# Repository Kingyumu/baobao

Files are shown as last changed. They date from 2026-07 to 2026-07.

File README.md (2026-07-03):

# 桌面天气站完整制作指南

> 从零到成品的制作手册：备齐材料 → 接线 → 编译烧录固件 → 装外壳 → 配网送礼。  
> 本文档**不包含项目源代码**，固件逻辑见仓库 `src/` 目录及源码注释。

**主控：** Raspberry Pi Pico 2 W（RP2350，板载 WiFi）  
**传感器：** BME280（温湿度气压）+ DS3231（RTC）  
**显示：** 3.5 寸 ILI9488 彩色 TFT（480×320）  
**交互：** 无源蜂鸣器 + TTP223 触摸

---

## 目录

1. [制作流程一览](#1-制作流程一览)
2. [成品功能说明](#2-成品功能说明)
3. [材料清单](#3-材料清单)
4. [开发环境搭建](#4-开发环境搭建)
5. [硬件接线](#5-硬件接线)
6. [固件说明（项目能做什么）](#6-固件说明项目能做什么)
7. [编译、烧录与首次验证](#7-编译烧录与首次验证)
8. [外壳制作与组装](#8-外壳制作与组装)
9. [送礼前可选配置](#9-送礼前可选配置)
10. [常见问题排查](#10-常见问题排查)
11. [附录 A：接线速查表](#附录-a接线速查表)
12. [附录 B：随礼使用说明书](#附录-b随礼使用说明书)

---

## 1. 制作流程一览

按顺序完成以下步骤，即可得到可送礼的成品：

| 步骤 | 做什么 | 预计时间 | 完成标志 |
| ----- | --- | --- | --- |
| ① 采购  | 按材料清单买齐模块与工具 | 1–3 天（等快递） | 所有模块到手 |
| ② 搭环境 | 安装 Rust、交叉编译工具链、probe-rs | 30–60 分钟 | `cargo`、`probe-rs` 命令可用 |
| ③ 接线  | 面包板或洞洞板连接各模块 | 30–60 分钟 | 对照检查清单全部打勾 |
| ④ 烧录  | 克隆项目、编译、写入 Pico 2 W | 15–30 分钟 | 屏幕出现启动动画 |
| ⑤ 配网  | 手机连热点、网页填家里 WiFi | 5 分钟 | 连上 WiFi，显示室外天气 |
| ⑥ 外壳  | 3D 打印或手工盒体，固定模块 | 1–2 小时 | 线材不 loose，屏幕对齐窗口 |
| ⑦ 送礼  | 打印附录 B 说明书，装盒 | 15 分钟 | 对方插电即用 |

**推荐顺序：** 先面包板裸机调通（③④⑤），确认功能正常后再做外壳（⑥），避免返工。

---

## 2. 成品功能说明

### 2.1 功能一览

| 功能 | 说明 | 是否需要 WiFi |
| --- | --- | --- |
| 室内温湿度 + 气压 | BME280 实时测量 | 否 |
| 精确时钟 | DS3231，断电靠纽扣电池走时 | 否（联网可 NTP 校准） |
| 圆形时钟 + 双页 UI | 轻触切换本地页 / 对方城市页；两页均保留时钟圆盘 | 否 |
| 双城室外天气 | 本地城市 + 对方城市（编译前配置城市码） | 是 |
| 表情动画 | 随温度、天气、气压趋势变化 | 部分依赖联网天气 |
| 室外天气 | 中国天气网，本地 + 对方两城数据 | 是 |
| 纪念日 / 生日 | 到日弹祝福 + 旋律 | 否 |
| 闹钟 / 整点报时 | 软件检测时间后蜂鸣 | 否 |
| 气压趋势与变天预警 | 本地气压趋势（变天预警仅本地页显示） | 否 |
| 触摸互动 | 短触切页；长按 2 秒爱心；长按 5 秒清除 WiFi | 否 |
| 手机配网 | 热点 + 网页，无需改代码烧录 | 首次或换 WiFi 时 |
| BLE 传感器广播 | 手机可连读室内温湿度（联网成功后开启） | 否（蓝牙独立） |

### 2.2 屏幕布局

设备共有 **两页**，左侧均为模拟时钟圆盘，右侧内容随页面切换。轻触一下在两页间来回切换。

**本地页（默认）**

```
┌──────────────────────────────────────────────────┐
│                                          [WiFi]  │
│          12                                      │
│        ·   ·       ☀ 余杭                        │
│      9  ⬡  3       室外 28°C · 晴                │
│        ·   ·       室内比室外凉 2.3°C             │
│          6         室内环境                       │
│                    😊 25.3°C  💧 45%             │
│       12:30:45     📊 1013 hPa  ↑ 转晴            │
│  室温曲线 (~2h)                   😊              │
│  ┌────────────────┐                             │
│  │    ～折线～     │                             │
│  └────────────────┘                             │
│             2026年7月1日 周二                      │
│ [本地] 轻触切换 长按爱心                            │
└──────────────────────────────────────────────────┘
```

**对方城市页**

```
┌──────────────────────────────────────────────────┐
│                                          [WiFi]  │
│          12                                      │
│        ·   ·       Ta在·北京                     │
│      9  ⬡  3       ☀ 22.5°C                     │
│        ·   ·       晴 · 湿度 40%                  │
│          6         比这里凉 5.5°C                 │
│                    我们在一起已经                  │
│       12:30:45        520天了                     │
│             2026年7月1日 周二                      │
│ [对方] 轻触切换 长按爱心                            │
└──────────────────────────────────────────────────┘
                        480 × 320
```

左侧：模拟时钟 + 数字时间 + **室温折线图**（约 2 小时，每分钟采样）  
右侧：本地页显示本城室外 + 室内环境；对方页显示 Ta 所在城市室外天气 + **在一起天数**（数字略大）  
右下：表情（本地页随本城环境，对方页随对方天气）  
底部：日期；左下角页码提示

### 2.3 系统结构（帮助理解接线）

```
  BME280 ──I2C──┐
  DS3231 ──I2C──┼──► Pico 2 W ──SPI──► ILI9488 屏幕
                │         │
  蜂鸣器 ──GPIO─┤         ├── WiFi（板载）──► 天气 / NTP
  触摸   ──GPIO─┘         └── BLE（板载，联网后广播传感器）
```

---

## 3. 材料清单

### 3.1 核心组件

| 物料  | 型号 | 数量  | 参考价 | 说明 |
| --- | --- | --- | --- | --- |
| 主控  | **Raspberry Pi Pico 2 W**  | 1 | ¥45 | 必须带 W（WiFi），RP2350 |
| 传感器 | **BME280 模块**（I2C，六脚） | 1 | ¥18 | 勿买成 BMP280（无湿度） |
| 显示屏 | **3.5 寸 ILI9488 TFT**（SPI） | 1 | ¥55 | 480×320，驱动 ILI9488 |
| 时钟  | **DS3231 模块**（带 CR2032） | 1 | ¥12 | I2C 地址 0x68 |
| 蜂鸣器 | **无源蜂鸣器模块** | 1 | ¥2  | 可播放旋律；有源只能「嘀」 |
| 触摸  | **TTP223 触摸模块** | 1 | ¥3  | 电容触摸，轻触即可 |

### 3.2 辅助材料

| 物料 | 数量 | 说明 |
| --- | ----- | --- |
| 面包板 830 孔 | 1 | 调试阶段用 |
| 杜邦线 公对母 / 公对公 | 20+ 根 | 你已有 40 根公对公通常够用 |
| USB **数据线** Type-C | 1 | 必须能传数据，不能纯充电线 |
| 3D 打印外壳或手工盒 | 1 套 | 见第 8 章 |
| 热熔胶 / 螺丝 | 若干 | 固定模块 |

**预算参考：** 约 ¥140–170（不含 3D 打印运费）

### 3.3 工具

- 电脑（Windows / macOS / Linux）
- 烙铁 + 焊锡（模块无排针时）
- 万用表（可选，查通断）
- 热熔胶枪（装外壳）

### 3.4 为什么选这些件

| 对比  | 不推荐 | 推荐 | 原因 |
| --- | --- | --- | --- |
| 主控  | Pico W (RP2040) | **Pico 2 W** | 520KB RAM 够驱动 3.5 寸彩屏 |
| 温湿度 | DHT11 | **BME280** | 精度高、I2C 稳定、带气压 |
| 屏幕  | 小 OLED | **3.5 寸 ILI9488** | 送礼观感好、480×320 彩色 |

---

## 4. 开发环境搭建

在**你自己的电脑**上完成（收礼人不需要装这些）。

### 4.1 安装 Rust

**Windows（PowerShell）：**

```powershell
winget install Rustlang.Rustup
```

或从 [https://www.rust-lang.org/tools/install](https://www.rust-lang.org/tools/install) 下载安装器。

**macOS / Linux：**

```bash
curl --proto '=https' --tlsv1.2 -sSf https://sh.rustup.rs | sh
```

验证：

```bash
rustc --version
cargo --version
```

### 4.2 安装嵌入式工具链

```bash
rustup target add thumbv8m.main-none-eabihf
cargo install probe-rs-tools
cargo install flip-link
```

### 4.3 Windows：USB 驱动（probe-rs 烧录）

1. 下载 [Zadig](https://zadig.akeo.ie/)
2. 按住 Pico **BOOTSEL**，插入 USB，松开
3. Zadig 中选择 Pico 设备，驱动选 **WinUSB**，安装

### 4.4 获取项目代码

```bash
git clone <你的仓库地址> baobao
cd baobao
```

### 4.5 环境自检

```bash
rustc --version
cargo --version
probe-rs --version
```

三项均有输出即可进入接线与烧录。

---

## 5. 硬件接线

### 5.1 原则

- **共地：** 所有模块 GND 接 Pico GND  
- **I2C 共享：** BME280 与 DS3231 共用 GP0(SDA)、GP1(SCL)，靠不同地址区分  
- **WiFi：** Pico 2 W 板载，**无需接线**  
- **屏幕 SPI：** 独立一组线，不要与 I2C 混接

### 5.2 接线总览图

```
                    Raspberry Pi Pico 2 W
                    ┌────────────────────────────────────┐
  3V3 (Pin36) ──┬──┼──────┬──────┬──────────┬──────────┼── ...
  GND (Pin38) ──┼──┼──────┼──────┼──────────┼──────────┼── ...
  GP0 (Pin1)  ──┼──┼──────┼──────┼──────────┼──────────┼── ...
  GP1 (Pin2)  ──┼──┼──────┼──────┼──────────┼──────────┼── ...
  GP6 (Pin9)  ──────────────────────────────────────────┼── ...
  GP7 (Pin10) ──────────────────────────────────────────┼── ...
  GP8~GP11    ──────────────────────────────────────────┼── SPI → TFT
                    └────────────────────────────────────┘
         │           │          │              │
    BME280+DS3231  蜂鸣器+触摸   ILI9488 TFT    WiFi 板载
```

### 5.3 引脚对照表

| Pico 引脚 | 功能 | 连接 |
| --- | --- | --- |
| GP0 (Pin1) | I2C SDA  | BME280 SDA、DS3231 SDA |
| GP1 (Pin2) | I2C SCL  | BME280 SCL、DS3231 SCL |
| GP6 (Pin6) | GPIO 出 | 蜂鸣器 I/O |
| GP7 (Pin7) | GPIO 入 | 触摸 I/O |
| GP8 (Pin8) | GPIO 出 | ILI9488 DC |
| GP9 (Pin9) | GPIO 出 | ILI9488 CS |
| GP10 (Pin10) | SPI SCK  | ILI9488 SCK |
| GP11 (Pin11) | SPI MOSI | ILI9488 MOSI |
| 3V3 (Pin36)  | 电源 | BME280、DS3231、触摸、TFT RST/LED 等 |
| 5V (Pin40) | 电源 | 部分 TFT 也可用 5V |
| GND (Pin38)  | 地 | 所有模块 GND |

### 5.4 各模块接线要点

**BME280：** VCC、GND、SDA、SCL 四线即可；确认芯片丝印为 BME280；I2C 地址一般为 **0x76**。

**DS3231：** 同上四线；装好 **CR2032** 纽扣电池；地址 **0x68**。

**ILI9488：** SCK、MOSI、CS、DC、VCC、GND；RST 与 LED 可接 3V3 常亮；MISO 可不接。模块丝印顺序可能不同，**以模块标注为准**。

**无源蜂鸣器：** I/O → GP6；VCC 建议 **5V**；GND 共地。

**TTP223：** I/O → GP7；触摸时输出高电平。

### 5.5 接线检查清单（烧录前必做）

- BME280、DS3231 的 SDA→GP0，SCL→GP1  
- ILI9488：SCK→GP10，MOSI→GP11，CS→GP9，DC→GP8  
- ILI9488 背光 LED、RST 接 3V3（或按模块说明）  
- 蜂鸣器 I/O→GP6  
- 触摸 I/O→GP7  
- 所有 GND 共地  
- DS3231 纽扣电池已装  
- USB 线为**数据线**

---

## 6. 固件说明（项目能做什么）

仓库里的固件是预写好的程序，你**不需要改代码也能做出成品**（配网用手机完成）。下面说明固件行为，方便排查问题。

### 6.1 项目里有哪些模块（仅文件名，方便查注释）

| 文件 | 作用 |
| --- | --- |
| `main.rs` | 启动流程、主循环、触摸逻辑 |
| `config.rs` | 城市码、纪念日、闹钟等可调参数 |
| `sensors.rs` | BME280、DS3231 驱动 |
| `display.rs` / `render.rs` | 屏幕驱动与界面绘制 |
| `network.rs` | WiFi、NTP、网络天气 |
| `wifi_store.rs` | Flash 保存最多 5 个 WiFi（最近使用的优先） |
| `provisioning.rs` | 热点 + 网页配网 |
| `state.rs` | 气压趋势、闹钟、纪念日等业务状态 |
| `buzzer.rs` | 提示音与旋律 |
| `ble.rs` | 蓝牙广播室内传感器（联网成功后启动） |

详细 Rust 学习注释见各文件顶部说明。

### 6.2 上电后发生什么

1. 屏幕显示 Loading 动画与「天气站启动中…」
2. 读取 Flash 里记住的 WiFi，**按最近使用顺序**逐个尝试连接
3. **若全部连不上** → 进入配网模式（见 7.3），此时**不开启 BLE**
4. **若连上** → 启动 BLE、NTP 对时、拉取天气 → 双声蜂鸣表示就绪
5. 进入主循环：每秒刷新显示，定期更新天气与 NTP

### 6.3 配网模式（送礼核心）

| 项目 | 内容 |
| ----- | --- |
| 热点名称  | `Baobao`（开放，无密码） |
| 设备 IP | `192.168.4.1` |
| 操作 | 手机连热点 → 浏览器打开上述 IP → 填家里 WiFi 名和密码 → 提交 |
| 成功 | 设备验证能连上 → 写入 Flash → 自动重启 → 正常模式 |
| 记忆 | 最多记住 **5 个** WiFi；满员时淘汰**最久未用**的网络 |
| 重新配网  | 长按触摸 **5 秒** → 清除全部 WiFi → 重启进入配网 |

屏幕配网页也会提示上述步骤。

### 6.4 触摸操作

| 操作 | 效果 |
| --- | --- |
| 短按 | 切换页面：本地 ↔ 对方城市（两页均保留时钟圆盘） |
| 长按约 2 秒 | 爱心动画 + 短促提示音 |
| 长按约 5 秒 | 两声长「嘀」→ 清除 WiFi 记忆 → 重启配网 |

### 6.5 网络相关

- **WiFi：** 仅 2.4GHz  
- **室外天气：** 中国天气网；烧录前在 `config.rs` 配置**本地城市码**与**对方城市码**（及显示名称）  
- **NTP：** 默认国家授时中心，联网后自动校准 DS3231  
- **断网：** 室内温湿度、时钟、表情、闹钟仍可用；室外天气不更新

### 6.6 表情与气压

- 表情随温度、网络天气、**气压趋势**变化  
- 气压持续下降且偏低时可能触发**变天预警**（屏幕提示 + 蜂鸣）  
- 不联网也能根据本地气压趋势显示「转晴 / 转阴」类提示

---

## 7. 编译、烧录与首次验证

### 7.1 编译

在项目根目录：

```bash
cargo check          # 快速检查
cargo build --release # 生成固件
```

### 7.2 烧录（推荐 probe-rs）

1. 按住 **BOOTSEL**，USB 连接电脑，松开
2. 执行：

```bash
cargo run --release
```

自动编译、烧录并运行。

**UF2 方式（无需 probe-rs）：**  
编译后找到 `target/thumbv8m.main-none-eabihf/release/weather_station.uf2`，BOOTSEL 模式下拖入 Pico 虚拟 U 盘。

### 7.3 首次验证清单

| 现象 | 是否正常 |
| --- | --- |
| 屏幕亮，有启动动画 | ✅ |
| 约 1 秒后双声蜂鸣  | ✅（已连上 WiFi 时） |
| 或进入配网界面 | ✅（Flash 无 WiFi 时，见 6.3） |
| 左侧时钟走动 | ✅（需 DS3231 正常；联网后 NTP 更准） |
| 室内温湿度有数值 | ✅（BME280 正常） |
| 短触屏幕有「嘀」且换页 | ✅ |

### 7.4 首次配网步骤（模拟收礼人操作）

1. 上电后若显示配网说明，用手机 WiFi 列表找到 **Baobao** 并连接
2. 浏览器访问 **[http://192.168.4.1](http://192.168.4.1)**（部分手机会自动弹出配网页）
3. 填写家里 **2.4GHz WiFi** 的名称和密码 → 保存
4. 等待「配网成功」→ 设备重启 → 应显示 WiFi 图标为已连接、室外温度出现

### 7.5 查看运行日志（排查用）

另开终端：

```bash
probe-rs attach --chip RP2350
```

正常时可见 BME280 初始化、WiFi 连接、NTP、天气等 INFO 日志（需固件开启 defmt）。

---

## 8. 外壳制作与组装

### 8.1 模块实测尺寸

先用卡尺量你手上每个模块的实际尺寸，以下为参考值：

| 模块 | 大约尺寸 (长×宽×高) | 备注 |
|---|---|---|
| ILI9488 3.5 寸屏 | 85 × 55 × 4 mm | 可视区约 73 × 49 mm |
| Pico 2 W | 51 × 21 × 4 mm | USB 口在一端 |
| BME280 模块 | 13 × 11 × 2 mm | 需要透气孔 |
| DS3231 模块 | 38 × 14 × 6 mm | 含纽扣电池座 |
| TTP223 触摸模块 | 24 × 16 × 2 mm | 金属感应面朝外 |
| 蜂鸣器模块 | 22 × 15 × 12 mm | 出声孔朝外 |

**外壳建议尺寸：** 100 × 80 × 40 mm（长 × 宽 × 高），壁厚 2mm。

### 8.2 外壳结构设计

外壳分**前面板**和**底壳**两部分（卡扣或螺丝合体）。

**前面板（屏幕面）**

```
┌──────────────────────────────────────┐
│  ┌────────────────────────────────┐  │
│  │                                │  │
│  │         屏幕窗口                │  │
│  │      75 × 51 mm               │  │
│  │   （比可视区四周大 1-2mm）        │  │
│  │                                │  │
│  └────────────────────────────────┘  │
│                                      │
│                 ◯ ← 触摸区           │
│              （TTP223 金属面对应位置） │
└──────────────────────────────────────┘
```

**底壳 / 后面**

```
┌──────────────────────────────────────┐
│                                      │
│  ◎ 透气孔 φ5-6mm   ← BME280 对应位置 │
│                                      │
│  □ USB Type-C 开口  ← Pico USB 对齐  │
│     约 9 × 4 mm                     │
│                                      │
│  ○ 出声孔 φ3-5mm × 2-3 个 ← 蜂鸣器  │
│                                      │
│  ⊚ 螺丝柱 M3 × 4（可选）            │
└──────────────────────────────────────┘
```

**必须开的孔/窗口：**

| 开孔 | 位置 | 尺寸 | 原因 |
|---|---|---|---|
| 屏幕窗口 | 前面板中央 | 75 × 51 mm | 显示内容可见 |
| USB 口 | 后面或侧面 | 9 × 4 mm | 供电线穿入 |
| 透气孔 | 底面，BME280 附近 | φ5-6 mm | 气压测量需空气流通 |
| 触摸区 | 前面板，TTP223 对应处 | 壁厚 ≤ 0.8mm 或开小孔 | 电容感应需手指靠近 |

**可选开孔：**

| 开孔 | 位置 | 尺寸 | 原因 |
|---|---|---|---|
| 蜂鸣器出声孔 | 侧面或底面 | φ3-5 mm × 2-3 个 | 声音更大 |
| 螺丝孔 | 四角 | M3 通孔 | 固定前后壳 |

### 8.3 方案选择

| 方案 | 难度  | 效果 | 费用 |
| --- | --- | --- | --- |
| 3D 打印 PLA | ★★☆ | 推荐，可定制触摸区与开孔 | 代打 ¥10–30  |
| 亚克力盒 | ★☆☆ | 快速，内部可见 | ¥5–15 |
| 纸盒 / 木盒 | ★☆☆ | 手工温馨感 | 几乎免费 |

无 3D 打印机可用嘉立创 3D 打印、淘宝代打，上传 STL 文件即可，约 ¥10–30。

### 8.4 建模工具（三选一）

**方案 A：TinkerCAD（零基础推荐，免费网页版）**

1. 打开 https://www.tinkercad.com → 注册 → 创建 3D 设计
2. 放一个 Box（100 × 80 × 40mm）作为外壳主体
3. 内部放一个 Hole Box（96 × 76 × 36mm）挖空（壁厚 2mm）
4. 前面放 Hole Box（75 × 51mm，深 2mm）挖屏幕窗口
5. 后面放 Hole Box（9 × 4mm）挖 USB 口
6. 底面放 Hole Cylinder（φ5mm）挖透气孔
7. 触摸区位置壁厚减薄到 0.8mm（或放 Hole Cylinder 开小圆孔）
8. 选中全部 → Group → 导出 `.stl`

**方案 B：Fusion 360（进阶推荐，免费个人版）**

1. 下载 https://www.autodesk.com/products/fusion-360/personal
2. 草绘外框矩形 → 拉伸 40mm
3. 草绘内框 → 拉伸做布尔减法挖空
4. 各面分别草绘开孔形状 → 拉伸切除
5. 可做卡扣、螺丝柱、加强筋等细节
6. 导出 `.stl`

**方案 C：用现成模型修改**

在 Printables（https://www.printables.com）或 Thingiverse 搜索：
- `"Pico weather station case"`
- `"3.5 inch TFT case"`
- `"ILI9488 enclosure"`

找接近的模型下载，在 TinkerCAD 或 MeshMixer 中修改尺寸和开孔。

### 8.5 打印参数建议

| 参数 | 推荐值 | 说明 |
|---|---|---|
| 材料 | PLA | 最易打印，室内够用 |
| 层高 | 0.2mm | 精度与速度平衡 |
| 填充 | 15–20% | 外壳不需要太实心 |
| 壁厚 | 2mm | 2–3 圈外壳，足够强度 |
| 支撑 | 有悬空时开启 | 屏幕窗口边缘可能需要 |
| 打印方向 | 底面朝下 | 屏幕窗口朝上打印，减少支撑 |

### 8.6 组装顺序

```
第 1 步：去支撑、打磨外壳
    ↓
第 2 步：固定 Pico（热熔胶或螺丝，USB 口对准后壳开孔）
    ↓
第 3 步：固定 TFT 屏幕（屏幕对准前窗，四周热熔胶固定）
    ↓
第 4 步：放置 BME280（对准透气孔，不要密封）
    ↓
第 5 步：固定 DS3231、蜂鸣器、触摸模块
         （触摸金属面朝向前壳指定位置）
    ↓
第 6 步：接线、理线，热熔胶加固避免短路
    ↓
第 7 步：合盖，底脚贴防滑垫
```

**注意事项：**

- BME280 **不能密封**，否则气压测量不准
- 触摸模块金属感应面必须**靠近壳体表面**（≤2mm），否则感应不灵敏
- 蜂鸣器出声孔要**朝外**，不能被其他模块挡住
- 热熔胶固定时**远离屏幕表面**，避免烫伤偏光片

### 8.7 送礼包装建议

- 打印 [附录 B](#附录-b随礼使用说明书) 放入盒内
- 附 USB Type-C 数据线、备用 CR2032 纽扣电池
- 盒内留简短手写卡片即可
- **无需**教对方改代码或烧录 — 设备用手机配网

---

## 9. 送礼前可选配置

以下在**烧录前**于电脑上改项目里的 `**src/config.rs`**，改完重新 `cargo run --release` 烧录。  
**WiFi 不必在此填写**——收礼人用手机配网即可。

| 配置项 | 用途 | 默认值提示 |
| --- | --- | --- |
| `CITY_CODE` / `LOCAL_CITY_NAME` | 设备所在城市码与显示名 | 可在 weather.com.cn 查 URL 中的数字 |
| `PARTNER_CITY_CODE` / `PARTNER_CITY_NAME` | 对方所在城市码与显示名 | 如异地恋场景填对方城市 |
| `LOVE_START_YEAR` / `MONTH` / `DAY` | 恋爱起始日（对方页「在一起 n 天」） | 含起始日当天为第 1 天 |
| `BIRTHDAY_MONTH` / `BIRTHDAY_DAY` | 生日祝福 | 改成对方生日 |
| `ANNIVERSARIES` | 情人节、纪念日等  | 可增删条目 |
| `ALARM_HOUR` / `ALARM_MINUTE` | 闹钟 | 可按需开关 `ALARM_ENABLED` |
| `HOURLY_CHIME_`* | 整点报时时段 | 默认 8:00–21:00 |
| `BLE_ENABLED` | 是否广播蓝牙传感器 | 默认关闭 |
| `WIFI_SSID` / `WIFI_PASSWORD` | 仅开发兜底 | 保持占位符即可，靠配网 |

**城市码查询：** 打开 [https://www.weather.com.cn/](https://www.weather.com.cn/) 搜索城市，地址栏如 `.../101210106.shtml` → 代码为 `101210106`。

---

## 10. 常见问题排查

### 10.1 编译 / 烧录

| 现象 | 处理 |
| --- | --- |
| `can't find crate for std` | 确认用 `cargo build --release`，目标为 `thumbv8m.main-none-eabihf` |
| `No connected probes` | 检查 USB 数据线、BOOTSEL、Windows 下 Zadig WinUSB |
| 烧录成功无显示 | `probe-rs attach` 看是否 panic；查 SPI 与背光接线 |

### 10.2 显示

| 现象 | 处理 |
| --- | --- |
| 不亮 | 查 TFT VCC、LED 背光是否接 3V3/5V |
| 白屏 / 花屏 | 查 SCK/MOSI/CS/DC；确认驱动为 **ILI9488** |
| 颜色不对 | 查 DC 线是否接错 |

### 10.3 传感器 / 时钟

| 现象 | 处理 |
| --- | --- |
| BME280 失败 | 查 I2C 线；确认 BME280 非 BMP280；试地址 0x76/0x77 |
| 读数偏高 | 传感器远离 Pico 发热区 |
| 时间不准 | 联网 NTP 校准；或 DS3231 换 CR2032 |

### 10.4 WiFi / 配网

| 现象 | 处理 |
| --- | --- |
| 一直配网界面 | 正常：Flash 无有效 WiFi；按 6.3 配网 |
| 配网提交失败 | 确认 2.4GHz、密码正确；路由器勿开「AP 隔离」 |
| 换路由器 | 再配一次新 WiFi 即可，旧 WiFi 仍保留在记忆里（最多 5 个） |
| 彻底重置 WiFi | 长按触摸 5 秒 |

### 10.5 触摸 / 蜂鸣

| 现象 | 处理 |
| --- | --- |
| 触摸无反应 | 查 GP7；用指腹大面积触摸金属面 |
| 只有「嘀」无旋律 | 确认是**无源**蜂鸣器；有源蜂鸣器无法播生日歌 |

---

## 附录 A：接线速查表

```
Pico 2 W          →  连接
────────────────────────────────────────
3V3  (Pin36)      →  BME280 VCC, DS3231 VCC, TTP223 VCC, TFT RST/LED
5V   (Pin40)      →  TFT VCC（视模块）
GND  (Pin38)      →  所有 GND
GP0  (Pin1)       →  BME280 SDA, DS3231 SDA
GP1  (Pin2)       →  BME280 SCL, DS3231 SCL
GP6  (Pin6)       →  蜂鸣器 I/O
GP7  (Pin7)       →  触摸 I/O
GP8  (Pin8)       →  ILI9488 DC
GP9  (Pin9)       →  ILI9488 CS
GP10 (Pin10)      →  ILI9488 SCK
GP11 (Pin11)      →  ILI9488 MOSI
（板载）          →  WiFi / BLE，无需外接线
```

---

## 附录 B：随礼使用说明书

> 可打印此页放入礼盒。收礼人**无需**安装软件或改代码。

---

### 🌤️ 桌面天气站 · 使用说明书

**亲爱的：**

这是我为你做的桌面天气站，插电即可使用。

---

#### 📦 它能做什么

- 显示室内**温度、湿度、气压**  
- 显示**时间**（断电后时钟电池仍走时）  
- 连接 WiFi 后显示**本地**与**对方城市**室外天气（送礼前已预设城市）  
- 会根据天气和温度变换**小表情**  
- 特殊日子会**播放旋律**  
- **轻触**顶部金属面可以互动

---

#### 🔌 第一次使用（约 5 分钟）

**1. 插电**  
用 USB 线连接充电器或电脑，屏幕会亮起。

**2. 连接 WiFi（首次必做）**  
若屏幕提示「WiFi 配网」：

1. 手机打开 WiFi，连接 **Baobao**（无密码）
2. 浏览器打开 **192.168.4.1**
3. 填写家里 **WiFi 名称**和**密码**（请选 **2.4G** 网络，不要用 5G 专用名）
4. 点保存，等待设备重启

成功后右上角 WiFi 图标变绿，会显示室外温度。

**3. 日常使用**  
之后每次插电会自动连上记住的 WiFi，**不用再配**。  
若搬新家或换了路由器，同样步骤再配一次即可。

**4. 重新配网 / 换 WiFi**  
长按触摸区 **约 5 秒**（两声长「嘀」），设备会清除 WiFi 并重启到配网界面。

---

#### 👆 触摸操作

| 操作 | 效果 |
| --- | --- |
| 轻触一下 | 在「本地」与「对方城市」两页间切换（两页都有时钟） |
| 长按约 2 秒 | 爱心动画 |
| 长按约 5 秒 | 清除 WiFi，进入重新配网 |

---

#### 😊 表情说明（简要）

表情会随室温、天气、气压变化；偶尔眨眼。详见屏幕右下角。

---

#### 🎂 特别日子

生日、情人节、圣诞、新年及预设纪念日当天，会弹出祝福并播放短旋律（具体日期已预设在设备内）。

---

#### ⚠️ 注意

- 请用 **5V** USB 供电，避免进水  
- 仅支持 **2.4GHz WiFi**  
- 时钟纽扣电池（CR2032）约 1–2 年更换一次

---

#### 🔧 小问题

| 现象 | 怎么办 |
| --- | --- |
| 屏幕不亮 | 重新插 USB |
| 没有室外天气 | 检查家里 WiFi；或重新配网 |
| 时间不准 | 连上 WiFi 后会自动校准  |
| 触摸不灵 | 用指腹多按一会儿金属面 |

---

**希望它每天陪在你身边。**

**爱你的人 ❤️**

---

**制作祝顺利。** 硬件与烧录问题见 [第 10 章](#10-常见问题排查)；想学习固件原理请阅读仓库 `src/` 下各文件注释。

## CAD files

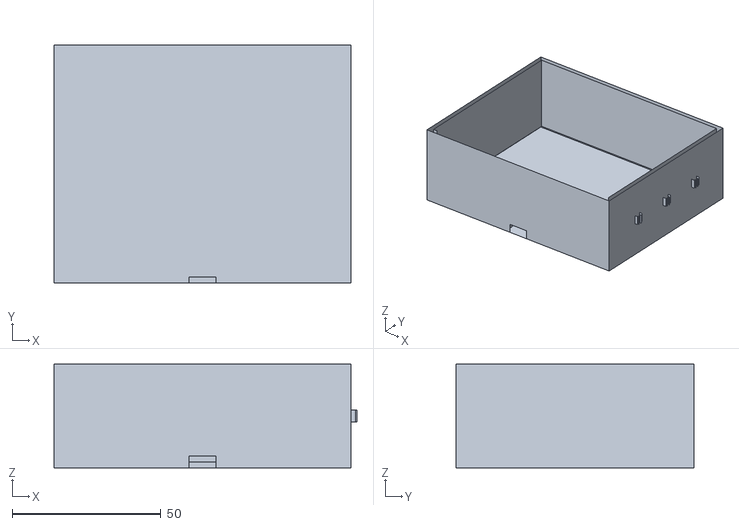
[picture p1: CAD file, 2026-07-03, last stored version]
bottom_shell.stl
102.0 x 80.0 x 35.0

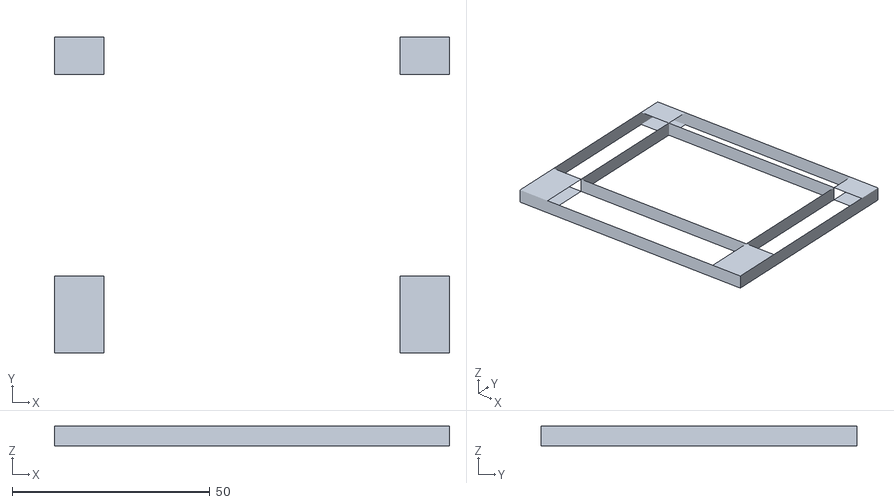
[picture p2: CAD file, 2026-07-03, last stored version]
front_panel.stl
100.0 x 80.0 x 5.00

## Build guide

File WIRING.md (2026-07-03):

# 桌面天气站接线指南

## 硬件清单

| 模块 | 型号 | 数量 | 供电 |
|---|---|---|---|
| 主控 | Raspberry Pi Pico 2 W | 1 | USB 5V |
| 温湿度气压传感器 | BME280 模块 | 1 | 3.3V |
| 实时时钟 | DS3231 模块 | 1 | 3.3V |
| TFT 彩屏 | ILI9488 3.5寸 480×320 | 1 | 5V (模块自带稳压) |
| 无源蜂鸣器 | 无源模块（板载 S9012 三极管） | 1 | 3.3V–5V |
| 触摸按钮 | 电容触摸模块 | 1 | 3.3V |

## Pico 2 W 引脚分配总览

```
          ┌─────────────────────┐
      GP0 │ 1              40│ VBUS (5V)
      GP1 │ 2              39│ VSYS
        — │ 3              38│ GND ←── 公共地
        — │ 4              37│ 3V3_EN
        — │ 5              36│ 3V3_OUT ←── 传感器供电
      GP6 │ 6  (蜂鸣器)  35│ ADC_VREF
      GP7 │ 7  (触摸)    34│ GP28
      GP8 │ 8  (屏DC)    33│ GP27
      GP9 │ 9  (屏CS)    32│ GP26
     GP10 │ 10 (屏SCLK)  31│ RUN
     GP11 │ 11 (屏MOSI)  30│ GP22
     GP12 │ 12           29│ GP21
     GP13 │ 13           28│ GND
     GP14 │ 14           27│ GP20
     GP15 │ 15           26│ GP19
     GP16 │ 16           25│ GP18
     GP17 │ 17           24│ GP17
        — │ 18           23│ GP16
        — │ 19           22│ GND
        — │ 20           21│ GP15
          └─────────────────────┘
```

## 详细接线

### 1. BME280（I2C 传感器）

| BME280 模块 | Pico 2 W | 说明 |
|---|---|---|
| VCC | 3V3_OUT (Pin 36) | **必须 3.3V，接 5V 会烧** |
| GND | GND (Pin 38) | |
| SDA | GP1 (Pin 2) | I2C0 SDA |
| SCL | GP0 (Pin 1) | I2C0 SCL |

> I2C 地址：SDO 接 GND 为 `0x76`（代码默认），接 VCC 为 `0x77`。

### 2. DS3231（RTC 实时时钟）

| DS3231 模块 | Pico 2 W | 说明 |
|---|---|---|
| VCC | 3V3_OUT (Pin 36) | **必须 3.3V** |
| GND | GND (Pin 38) | |
| SDA | GP1 (Pin 2) | 与 BME280 共用 I2C 总线 |
| SCL | GP0 (Pin 1) | 与 BME280 共用 I2C 总线 |

> DS3231 模块自带纽扣电池，断电后时间不丢失。
> I2C 地址：`0x68`（固定，不会与 BME280 冲突）。

### 3. ILI9488 TFT 彩屏（SPI）

| ILI9488 模块 | Pico 2 W | 说明 |
|---|---|---|
| VCC | VBUS (Pin 40) | 5V，模块自带 3.3V 稳压 |
| GND | GND (Pin 38) | |
| SCL / SCLK | GP10 (Pin 10) | SPI1 时钟 |
| SDI / MOSI | GP11 (Pin 11) | SPI1 数据 |
| CS | GP9 (Pin 9) | 片选（软件控制） |
| DC / RS | GP8 (Pin 8) | 数据/命令选择 |
| RESET | 3V3 或悬空 | 复位引脚，接高或悬空 |
| LED / BL | VBUS 或独立控制 | 背光，直接接 5V 常亮 |
| MISO | GP12 (Pin 12) | **不接**（屏只写不读） |

> SPI1 代码中初始化了 MISO (GP12)，但实际未使用，屏的 MISO 可以不接。

### 4. 无源蜂鸣器模块（板载三极管，直连 GPIO）

模块**自带 S9012 三极管 + 限流电阻**，GPIO 直接驱动，无需外接元件。

| 蜂鸣器模块 | Pico 2 W | 说明 |
|---|---|---|
| VCC | 3V3 (Pin 36) 或 VBUS (Pin 40) | 3.3V–5V 均可 |
| GND | GND (Pin 38) | |
| I/O | GP6 (Pin 6) | 高电平触发，方波驱动发声 |

### 5. 触摸按钮

| 触摸模块 | Pico 2 W | 说明 |
|---|---|---|
| VCC | 3V3_OUT (Pin 36) | |
| GND | GND (Pin 38) | |
| SIG / OUT | GP7 (Pin 7) | 触摸信号输出 |

> 代码中配置了内部下拉电阻 (`Pull::Down`)，触摸时输出高电平。

## 接线顺序（安全操作）

```
第 1 步：断开 USB，确认 Pico 未通电
    ↓
第 2 步：接 GND 线 — 所有模块的 GND 先连到 Pico 的 GND
    ↓
第 3 步：接电源线 — 3V3_OUT 给传感器，VBUS 给屏幕
    ↓
第 4 步：接信号线 — I2C / SPI / GPIO
    ↓
第 5 步：目视检查 — 有无短路、虚焊、错接
    ↓
第 6 步：万用表测 VCC 与 GND 是否短路
    ↓
第 7 步：插 USB 上电
```

## 常见烧毁场景与预防

| 场景 | 后果 | 预防 |
|---|---|---|
| BME280/DS3231 接 5V | 芯片烧毁 | 确认接 3V3_OUT，不是 VBUS |
| I2C 接线时热插拔 | IO 闩锁烧毁 | 断电后再改线 |
| SPI 屏 VCC 接 3.3V | 可能不亮（背光电流大） | 屏幕接 VBUS (5V) |
| GND 没共地 | 通信不稳定或损坏 | 所有模块 GND 必须连在一起 |

## 检查清单

- [ ] 所有模块 GND 已共地
- [ ] BME280 和 DS3231 接 3.3V，不是 5V
- [ ] ILI9488 接 5V (VBUS)
- [ ] I2C 只有两根线（SDA、SCL），没有接反
- [ ] 蜂鸣器模块 I/O 接 GP6
- [ ] 触摸模块信号线接 GP7
- [ ] 无裸露导线短路风险
- [ ] 万用表测量 VCC-GND 无短路

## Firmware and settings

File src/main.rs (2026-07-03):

#![no_std]
#![no_main]
#![allow(linker_messages)]

//! 桌面天气站主程序 — Raspberry Pi Pico 2 W (RP2350)
//!
//! ## 程序结构
//! 1. 初始化硬件（I2C / SPI 屏 / WiFi / Flash）
//! 2. 尝试连接已记住的 WiFi；失败则进入 [`provisioning`] 配网（此阶段不启动 BLE）
//! 3. 进入主循环：读传感器 → 更新状态 → 按需联网 → 刷新屏幕
//!
//! ## Rust / Embassy 实战要点
//! - `#![no_std]`：不用标准库，适合 MCU；需要堆时用 `extern crate alloc`
//! - `#![no_main]`：入口由 `#[embassy_executor::main]` 宏生成，不是普通 `fn main()`
//! - `async/await`：等待 I2C、WiFi、定时器时不阻塞 CPU，Embassy 协作式调度
//! - `'static`：spawn 出去的任务、GPIO 引脚要求「整个程序生命周期有效」
//! - [`StaticCell`]：在运行时安全地给 `static` 变量做**一次性**初始化
//! - [`Mutex`] + `.lock().await`：BME280 与 DS3231 共用 I2C 时的异步互斥锁
//! - [`Option`] / [`match`]：Rust 用类型系统表达「可能有值」，避免空指针
//! - `-> !`（如 [`wifi_store::sys_reset`]）：表示函数永不返回

extern crate alloc;

mod ble;
mod buzzer;
mod config;
mod display;
mod i2c_bus;
mod network;
mod provisioning;
mod render;
mod sensors;
mod state;
mod wifi_store;

use ble::publish_snapshot;
use buzzer::{alert_beep, beep, hourly_chime, melody, melody_for_event, ALARM_MELODY};
use defmt::*;
use display::{draw_special_event, face_color, theme_for_hour, Face, FaceType, Ili9488Display};
use embassy_executor::Spawner;
use embassy_rp::flash::Flash;
use embassy_rp::gpio::{Input, Level, Output, Pull};
use embassy_rp::i2c::{self, Config as I2cConfig};
use embassy_rp::spi::{Config as SpiConfig, Spi};
use embassy_sync::mutex::Mutex;
use embassy_time::{Duration, Instant, Timer};
use embedded_graphics::{
    mono_font::{ascii::FONT_10X20, MonoTextStyleBuilder},
    prelude::*,
    text::Text,
};
use i2c_bus::{I2cBus, I2cIrqs};
use network::{connect_wifi, fetch_weather, init_wifi, sync_ntp};
use render::RenderCache;
use sensors::{Bme280, DateTime, Ds3231};
use state::SystemState;
use static_cell::StaticCell;
use trouble_host::prelude::ExternalController;
use panic_probe as _;

#[global_allocator]
// 堆分配器：供 alloc::format! 等少量动态内存使用（131072 = 128 KiB）
static HEAP: embedded_alloc::LlffHeap = embedded_alloc::LlffHeap::empty();

/// 长按触摸时播放爱心动画（局部重绘，不整屏刷新）。
async fn show_touch_heart(display: &mut Ili9488Display, hour: u8) {
    let bg = theme_for_hour(hour).bg;
    let mut heart = Face::new(FaceType::Heart);
    for _ in 0..4 {
        display.fill_rect(380, 215, 32, 32, bg.into_storage());
        heart.draw_scaled(display, 380, 215, 4, face_color(FaceType::Heart));
        Timer::after_millis(250).await;
        heart.next_frame();
    }
}

/// 纪念日/生日：蜂鸣旋律 + 全屏提示 + 爱心动画，每天只触发一次（由 state 去重）。
async fn handle_special_event(
    display: &mut Ili9488Display,
    buzzer: &mut Output<'static>,
    cache: &mut RenderCache,
    state: &mut SystemState,
) {
    let ev = match state.special_event {
        Some(ev) if state.should_handle_special_event() => ev,
        _ => return,
    };

    info!("特殊事件: {}", ev);
    state.mark_special_event_handled();

    melody(buzzer, melody_for_event(ev)).await;

    draw_special_event(display, ev);
    let mut heart = Face::new(FaceType::Heart);
    for _ in 0..5 {
        heart.draw_scaled(display, 220, 200, 6, face_color(FaceType::Heart));
        Timer::after_millis(500).await;
        heart.next_frame();
    }
    cache.invalidate();
}

/// BLE 协议栈独立任务：与主循环并行，通过 [`ble::publish_snapshot`] 读传感器快照。
#[embassy_executor::task]
async fn ble_host_task(bt_device: cyw43::bluetooth::BtDriver<'static>) {
    let controller: ExternalController<_, 10> = ExternalController::new(bt_device);
    ble::run(controller).await;
}

#[embassy_executor::main]
async fn main(spawner: Spawner) {
    // 初始化堆：MaybeUninit 避免在 const 上下文要求未初始化数组为 0
    {
        use core::mem::MaybeUninit;
        static mut HEAP_MEM: [MaybeUninit<u8>; 131072] = [MaybeUninit::uninit(); 131072];
        #[allow(static_mut_refs)]
        unsafe {
            HEAP.init(HEAP_MEM.as_mut_ptr() as usize, 131072);
        }
    }

    let p = embassy_rp::init(Default::default());
    info!("桌面天气站启动中...");

    // I2C 总线用 Mutex 包装：多个 async 调用方串行访问，避免并发读写冲突
    let i2c = i2c::I2c::new_async(p.I2C0, p.PIN_1, p.PIN_0, I2cIrqs, I2cConfig::default());
    static I2C_BUS: StaticCell<I2cBus> = StaticCell::new();
    let bus = I2C_BUS.init(Mutex::new(i2c));

    // SPI 屏用 blocking 模式：draw 在主循环里同步刷像素，实现简单
    let spi = Spi::new_blocking(p.SPI1, p.PIN_10, p.PIN_11, p.PIN_12, SpiConfig::default());
    let dc = Output::new(p.PIN_8, Level::Low);
    let cs = Output::new(p.PIN_9, Level::Low);

    let mut display = Ili9488Display::new(spi, dc, cs);
    display.init();
    let boot_theme = theme_for_hour(12);
    display.clear(boot_theme.bg);
    {
        let mut loading = Face::new(FaceType::Loading);
        for _ in 0..6 {
            display.clear(boot_theme.bg);
            loading.draw_scaled(&mut display, 216, 120, 6, face_color(FaceType::Loading));
            let ts = MonoTextStyleBuilder::new()
                .font(&FONT_10X20)
                .text_color(boot_theme.text)
                .build();
            Text::new("天气站启动中...宝宝我爱你❤", Point::new(140, 220), ts)
                .draw(&mut display)
                .ok();
            loading.next_frame();
            Timer::after_millis(300).await;
        }
    }

    let mut bme = Bme280::new();
    match bme.init(bus).await {
        Ok(()) => info!("BME280 初始化成功"),
        Err(e) => warn!("BME280 初始化失败: {:?}", e),
    }

    let rtc = Ds3231::new();
    let mut buzzer = Output::new(p.PIN_6, Level::Low);
    let touch = Input::new(p.PIN_7, Pull::Down);
    let mut flash = Flash::new_blocking(p.FLASH);

    let (mut wifi_control, stack, bt_device) = init_wifi(
        &spawner,
        p.PIO0,
        p.DMA_CH0,
        p.DMA_CH1,
        p.PIN_23,
        p.PIN_24,
        p.PIN_25,
        p.PIN_29,
    )
    .await;

    let wifi_connected = connect_wifi(&mut wifi_control, stack, &mut flash).await;

    // 全部记住的网络都连不上 → 开热点配网；`run` 成功后会 reboot，正常不会返回
    if !wifi_connected {
        provisioning::run(
            &mut display,
            &mut wifi_control,
            stack,
            &spawner,
            &mut flash,
            &mut buzzer,
        )
        .await;
    }

    // 仅联网成功后才启动 BLE，配网阶段关闭蓝牙以降低复杂度
    if config::BLE_ENABLED {
        if let Some(bt) = bt_device {
            spawner.spawn(ble_host_task(bt).unwrap());
            info!("BLE 传感器广播已启动");
        }
    }

    let mut state = SystemState::new();
    let mut render_cache = RenderCache::new();
    state.wifi_connected = wifi_connected;

    if wifi_connected && sync_ntp(stack, &rtc, bus).await {
        state.last_ntp_sync = 0;
    }

    if wifi_connected {
        match fetch_weather(stack, config::CITY_CODE).await {
            Some(w) => {
                info!(
                    "本地天气: {}°C {} [{}]",
                    w.temp,
                    w.text.as_str(),
                    w.weather_code.as_str()
                );
                state.set_weather_code(w.weather_code.as_str());
                state.network_weather = Some(w);
            }
            None => warn!("首次本地天气获取失败"),
        }
        match fetch_weather(stack, config::PARTNER_CITY_CODE).await {
            Some(w) => {
                info!(
                    "对方天气: {}°C {} [{}]",
                    w.temp,
                    w.text.as_str(),
                    w.weather_code.as_str()
                );
                state.partner_weather = Some(w);
            }
            None => warn!("首次对方天气获取失败"),
        }
    }

    Timer::after_secs(1).await;
    info!("桌面天气站启动成功！");
    beep(&mut buzzer, 100).await;
    Timer::after_millis(50).await;
    beep(&mut buzzer, 100).await;

    // 触摸状态机：短按切页 / 2s 长按爱心 / 5s 长按清除 WiFi 并重启
    let mut touch_pressed = false;
    let mut touch_down: Option<Instant> = None;
    let mut touch_long_done = false;
    let mut touch_clear_done = false;
    let mut last_wifi_reconnect = 0u64;
    let long_press = Duration::from_millis(config::TOUCH_LONG_PRESS_MS);
    let clear_wifi_press = Duration::from_millis(config::TOUCH_CLEAR_WIFI_MS);

    loop {
        let loop_start = embassy_time::Instant::now().as_secs();

        // 链路断开时按间隔重连，会依次尝试 Flash 里记住的全部 WiFi
        let link_up = stack.is_config_up();
        state.wifi_connected = link_up;
        if !link_up {
            if loop_start.saturating_sub(last_wifi_reconnect) >= config::WIFI_RECONNECT_INTERVAL {
                last_wifi_reconnect = loop_start;
                info!("WiFi 断开，尝试重连...");
                if connect_wifi(&mut wifi_control, stack, &mut flash).await {
                    state.wifi_connected = true;
                    state.last_ntp_sync = 0;
                    state.last_weather_update = 0;
                    render_cache.invalidate();
                }
            }
        }

        match bme.measure(bus).await {
            Ok(m) => {
                state.temperature = m.temperature;
                state.humidity = m.humidity;
                state.update_pressure(m.pressure);
                if config::BLE_ENABLED {
                    publish_snapshot(m.temperature, m.humidity, m.pressure);
                }
            }
            Err(e) => warn!("BME280 读取失败: {:?}", e),
        }

        match rtc.get_time(bus).await {
            Ok(t) => state.update_time(t),
            Err(e) => warn!("DS3231 读取失败: {:?}", e),
        }

        state.sample_temp_chart(loop_start);

        if let Some(t) = state.current_time {
            if state.check_hourly_chime(&t) {
                hourly_chime(&mut buzzer).await;
            }
            if state.check_alarm(&t) {
                melody(&mut buzzer, &ALARM_MELODY).await;
            }
        }

        if state.check_weather_alert(loop_start) {
            state.activate_weather_alert(loop_start);
            alert_beep(&mut buzzer).await;
            render_cache.invalidate();
        }
        state.tick_weather_alert(loop_start);

        let touch_hour = state
            .current_time
            .map(|t| t.hour)
            .unwrap_or(12);

        if touch.is_high() {
            if !touch_pressed {
                touch_pressed = true;
                touch_down = Some(Instant::now());
                touch_long_done = false;
                touch_clear_done = false;
            } else if !touch_clear_done && !touch_long_done {
                if let Some(down) = touch_down {
                    let held = down.elapsed();
                    if held >= clear_wifi_press {
                        info!("清除 WiFi 配置，进入配网模式...");
                        beep(&mut buzzer, 100).await;
                        Timer::after_millis(80).await;
                        beep(&mut buzzer, 100).await;
                        let _ = wifi_store::clear(&mut flash);
                        wifi_store::sys_reset();
                    } else if held >= long_press {
                        touch_long_done = true;
                        beep(&mut buzzer, 30).await;
                        show_touch_heart(&mut display, touch_hour).await;
                        render_cache.invalidate();
                    }
                }
            }
        } else if touch_pressed {
            if !touch_long_done && !touch_clear_done {
                state.next_page();
                info!("切换页面: {}", state.display_page.label());
                beep(&mut buzzer, 50).await;
                render_cache.invalidate();
            }
            touch_pressed = false;
            touch_down = None;
        }

        handle_special_event(&mut display, &mut buzzer, &mut render_cache, &mut state).await;

        if state.wifi_connected
            && loop_start - state.last_weather_update >= config::WEATHER_UPDATE_INTERVAL
        {
            let mut updated = false;
            if let Some(w) = fetch_weather(stack, config::CITY_CODE).await {
                info!(
                    "本地天气: {}°C {} [{}]",
                    w.temp,
                    w.text.as_str(),
                    w.weather_code.as_str()
                );
                state.set_weather_code(w.weather_code.as_str());
                state.network_weather = Some(w);
                updated = true;
            } else {
                warn!("本地天气获取失败");
            }
            if let Some(w) = fetch_weather(stack, config::PARTNER_CITY_CODE).await {
                info!(
                    "对方天气: {}°C {} [{}]",
                    w.temp,
                    w.text.as_str(),
                    w.weather_code.as_str()
                );
                state.partner_weather = Some(w);
                updated = true;
            } else {
                warn!("对方天气获取失败");
            }
            if updated {
                state.last_weather_update = loop_start;
            }
        }

        if state.wifi_connected && loop_start - state.last_ntp_sync >= config::NTP_SYNC_INTERVAL {
            if sync_ntp(stack, &rtc, bus).await {
                state.last_ntp_sync = loop_start;
            }
        }

        let time = state.current_time.unwrap_or(DateTime {
            year: 2026,
            month: 1,
            day: 1,
            weekday: 3,
            hour: 0,
            minute: 0,
            second: 0,
        });

        render_cache.update(&mut display, &state, &time);

        state.animation_counter += 1;
        Timer::after_secs(config::DISPLAY_UPDATE_INTERVAL).await;
    }
}

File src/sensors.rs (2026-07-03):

//! I2C 传感器驱动 — BME280（温湿度气压）与 DS3231（RTC）。
//!
//! ## 通信模式
//! 所有方法通过 [`I2cBus`]（Mutex 包装的 async I2C）访问硬件：
//! `bus.lock().await` 获取独占访问权后再 `write` / `write_read`。
//!
//! ## Rust 要点
//! - `embedded_hal_async::i2c::I2c` trait：抽象 I2C 读写，与具体 HAL 解耦
//! - `Option<Calib>`：校准系数读一次后缓存，避免每次测量都读寄存器
//! - `Result<T, E>`：I2C 失败时返回 [`i2c::Error`]，调用方用 `match` 处理

use crate::i2c_bus::I2cBus;
use defmt::*;
use embassy_rp::i2c;
use embassy_time::{Duration, Timer};
use embedded_hal_async::i2c::I2c;

/// 统一的时间结构（与 DS3231 寄存器字段对应）。
#[derive(Debug, Clone, Copy)]
pub struct DateTime {
    pub year: u16,
    pub month: u8,
    pub day: u8,
    pub hour: u8,
    pub minute: u8,
    pub second: u8,
    pub weekday: u8,
}

/// 单次 BME280 测量结果。
pub struct Measurements {
    pub temperature: f32,
    pub pressure: f32,
    pub humidity: f32,
}

/// Bosch 数据手册中的补偿参数（从芯片 OTP 读出）。
struct Calib {
    t1: u16,
    t2: i16,
    t3: i16,
    p1: u16,
    p2: i16,
    p3: i16,
    p4: i16,
    p5: i16,
    p6: i16,
    p7: i16,
    p8: i16,
    p9: i16,
    h1: u8,
    h2: i16,
    h3: u8,
    h4: i16,
    h5: i16,
    h6: i8,
    t_fine: i32, // 温度补偿中间值，湿度补偿会用到
}

pub struct Bme280 {
    addr: u8,
    cal: Option<Calib>,
}

impl Bme280 {
    pub fn new() -> Self {
        Self {
            addr: 0x76, // SDO 接 GND；接 VCC 时为 0x77
            cal: None,
        }
    }

    async fn read_regs(&self, bus: &I2cBus, reg: u8, buf: &mut [u8]) -> Result<(), i2c::Error> {
        bus.lock().await.write_read(self.addr, &[reg], buf).await
    }

    async fn write_reg(&self, bus: &I2cBus, reg: u8, val: u8) -> Result<(), i2c::Error> {
        bus.lock().await.write(self.addr, &[reg, val]).await
    }

    /// 软复位 → 读校准系数 → 配置 oversampling 与 standby。
    pub async fn init(&mut self, bus: &I2cBus) -> Result<(), i2c::Error> {
        let mut id = [0u8];
        self.read_regs(bus, 0xD0, &mut id).await?;
        info!("BME280 芯片ID: 0x{:02X}", id[0]);
        self.write_reg(bus, 0xE0, 0xB6).await?; // soft reset
        Timer::after(Duration::from_millis(10)).await;
        let mut pt = [0u8; 26];
        self.read_regs(bus, 0x88, &mut pt).await?;
        let mut h = [0u8; 7];
        self.read_regs(bus, 0xE1, &mut h).await?;
        // 小端序拼接 16 位校准寄存器
        self.cal = Some(Calib {
            t1: u16::from_le_bytes([pt[0], pt[1]]),
            t2: i16::from_le_bytes([pt[2], pt[3]]),
            t3: i16::from_le_bytes([pt[4], pt[5]]),
            p1: u16::from_le_bytes([pt[6], pt[7]]),
            p2: i16::from_le_bytes([pt[8], pt[9]]),
            p3: i16::from_le_bytes([pt[10], pt[11]]),
            p4: i16::from_le_bytes([pt[12], pt[13]]),
            p5: i16::from_le_bytes([pt[14], pt[15]]),
            p6: i16::from_le_bytes([pt[16], pt[17]]),
            p7: i16::from_le_bytes([pt[18], pt[19]]),
            p8: i16::from_le_bytes([pt[20], pt[21]]),
            p9: i16::from_le_bytes([pt[22], pt[23]]),
            h1: pt[25],
            h2: i16::from_le_bytes([h[0], h[1]]),
            h3: h[2],
            h4: ((h[3] as i16) << 4) | ((h[4] as i16) & 0x0F),
            h5: ((h[5] as i16) << 4) | ((h[4] as i16) >> 4),
            h6: h[6] as i8,
            t_fine: 0,
        });
        self.write_reg(bus, 0xF2, 0x01).await?; // humidity oversampling x1
        self.write_reg(bus, 0xF4, 0x27).await?; // temp x1, pressure x1, normal mode
        self.write_reg(bus, 0xF5, 0xA0).await?; // standby 1000ms, filter off
        Ok(())
    }

    /// 触发 forced 模式测量，等待后读原始 ADC 并补偿。
    pub async fn measure(&mut self, bus: &I2cBus) -> Result<Measurements, i2c::Error> {
        self.write_reg(bus, 0xF4, 0x25).await?; // forced mode
        Timer::after(Duration::from_millis(50)).await;
        let mut data = [0u8; 8];
        self.read_regs(bus, 0xF7, &mut data).await?;
        let cal = self.cal.as_mut().unwrap();
        // 20 位 ADC 原始值（数据手册位域拼接）
        let raw_p =
            ((data[0] as u32) << 12) | ((data[1] as u32) << 4) | ((data[2] as u32) >> 4);
        let raw_t =
            ((data[3] as u32) << 12) | ((data[4] as u32) << 4) | ((data[5] as u32) >> 4);
        let raw_h = ((data[6] as u32) << 8) | (data[7] as u32);
        let t = Self::comp_t(raw_t, cal);
        let p = Self::comp_p(raw_p, cal);
        let h = Self::comp_h(raw_h, cal);
        Ok(Measurements {
            temperature: t,
            pressure: p,
            humidity: h,
        })
    }

    /// 温度补偿（官方公式，会更新 cal.t_fine 供湿度用）。
    fn comp_t(raw: u32, c: &mut Calib) -> f32 {
        let v1 = (raw as f32 / 16384.0 - c.t1 as f32 / 1024.0) * c.t2 as f32;
        let v2 = raw as f32 / 131072.0 - c.t1 as f32 / 8192.0;
        let v2 = v2 * v2 * c.t3 as f32;
        c.t_fine = (v1 + v2) as i32;
        (v1 + v2) / 5120.0
    }

    fn comp_p(raw: u32, c: &mut Calib) -> f32 {
        let tf = c.t_fine as f32;
        let v1 = tf / 2.0 - 64000.0;
        let v2 = v1 * v1 * c.p6 as f32 / 32768.0 + v1 * c.p5 as f32 * 2.0;
        let v2 = v2 / 4.0 + c.p4 as f32 * 65536.0;
        let v3 = c.p3 as f32 * v1 * v1 / 524288.0;
        let v1 = (v3 + c.p2 as f32 * v1) / 524288.0;
        let v1 = (1.0 + v1 / 32768.0) * c.p1 as f32;
        if v1 > 0.0 {
            let p = 1048576.0 - raw as f32;
            let p = (p - v2 / 4096.0) * 6250.0 / v1;
            let v1 = c.p9 as f32 * p * p / 2147483648.0;
            let v2 = p * c.p8 as f32 / 32768.0;
            (p + (v1 + v2 + c.p7 as f32) / 16.0) / 100.0
        } else {
            0.0
        }
    }

    fn comp_h(raw: u32, c: &mut Calib) -> f32 {
        let tf = c.t_fine as f32;
        let v1 = tf - 76800.0;
        let v2 = c.h4 as f32 * 64.0 + (c.h5 as f32 / 16384.0) * v1;
        let v3 = raw as f32 - v2;
        let v4 = c.h2 as f32 / 65536.0;
        let v5 = 1.0 + (c.h3 as f32 / 67108864.0) * v1;
        let v6 = 1.0 + (c.h6 as f32 / 67108864.0) * v1 * v5;
        let h = v3 * v4 * (v5 * v6) * (1.0 - c.h1 as f32 * v3 * v4 * (v5 * v6) / 524288.0);
        h.clamp(0.0, 100.0)
    }
}

pub struct Ds3231 {
    addr: u8,
}
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

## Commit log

2026-07-02 Initial commit: Pico 2 W desktop weather station with Embassy Rust firmware and build guide.
2026-07-02 Add touch page switching, comfort metrics, dew point, and night theme.
2026-07-02 Add alarm, hourly chime, pressure chart, weather alert, and event melodies.
2026-07-02 Add BLE GATT sensor broadcasting alongside WiFi on Pico 2 W.
2026-07-03 Refactor UI to dual local/partner pages with dual-city weather and together-days counter.
    Replace the three-page cycle with clock-plus-panel local and partner views, fetch both cities on a shared interval, compute love days from LOVE_START in state, and rewrite the build guide as a materials-to-product workflow doc.
    [display.rs, main.rs, network.rs]
2026-07-03 Replace unused pressure chart with a two-hour indoor temperature sparkline on the local page.
    Sample BME280 temperature every minute into a 120-point ring buffer and render it below the clock; update the build guide layout accordingly.
    [display.rs, main.rs]
2026-07-03 Rename 桌面天气站完整制作指南.md to README.md for standard project documentation naming.
2026-07-03 Add love message to boot screen: 宝宝我爱你❤
2026-07-03 Update wiring docs: buzzer module has onboard S9012 transistor, fix physical pin numbers
2026-07-03 Rewrite section 8: detailed 3D printing enclosure guide with dimensions, structure, tools, and assembly
2026-07-03 Add 3D printable STL files for enclosure (front panel + bottom shell)
    [bottom_shell.stl, front_panel.stl]
2026-07-03 Fix STL generation: proper screen window cutout and hollow shell with USB/vent/buzzer holes
    [bottom_shell.stl, front_panel.stl]
2026-07-03 Remove unused STL files and generator script
    [bottom_shell.stl, front_panel.stl]
